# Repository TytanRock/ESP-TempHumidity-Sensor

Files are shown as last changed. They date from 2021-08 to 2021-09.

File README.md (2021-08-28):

# ESP Based IoT reporter
Project and Source files for custom PCB that implements various sensors with an ESP for reporting

## Sponsored by PCBWay
This project was graciously sponsored by [PCBWay](https://www.pcbway.com/) who provided boards of the product. I've used them before and enjoy their service, as they provide an affordable way of creating professional PCBs for projects such as this one. Check them out!

## Purpose
This is mostly a learning exercise for more complex boards, and tighter integration with cloud stuff.
I wanted to make a board that uses an ESP8266 to measure various things and report them to a cloud service.
This first version includes just measuring temperature and humidity throughout the house, with the option to expand and measure other things through I2C or Analog.

It includes an FTDI chip to program the ESP, the ESP itself, a temp/humidity sensor, and a Lithium-Ion charger with a connector for a Li-ion battery if I want to place it somewhere out of reach.
The repo will also include source code once I get my first batch of boards in.

## Board Views
I don't have the physical boards currently, but I think it's always nice to see what the boards look like without downloading and viewing it through eagle.
So here's the Top and Bottom boardview from Eagle.

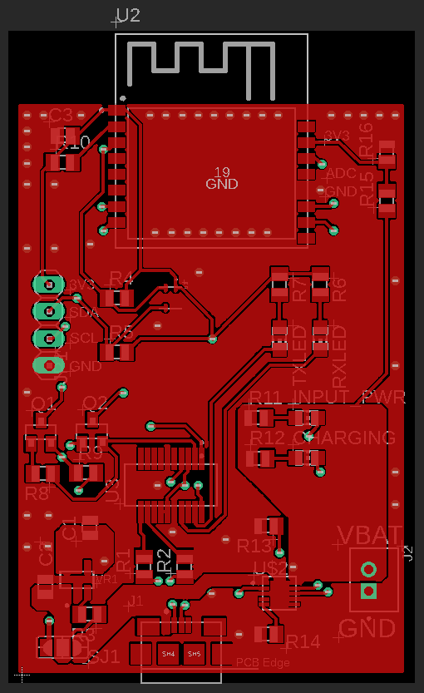
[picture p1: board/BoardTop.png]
Top Board

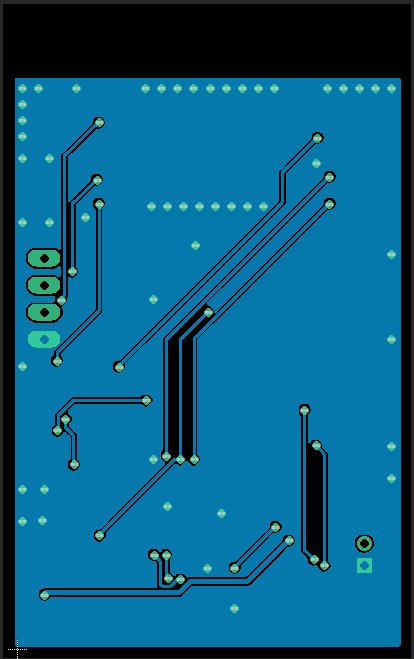
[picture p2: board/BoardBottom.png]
Bottom Board


Have fun with it if you think it's cool.

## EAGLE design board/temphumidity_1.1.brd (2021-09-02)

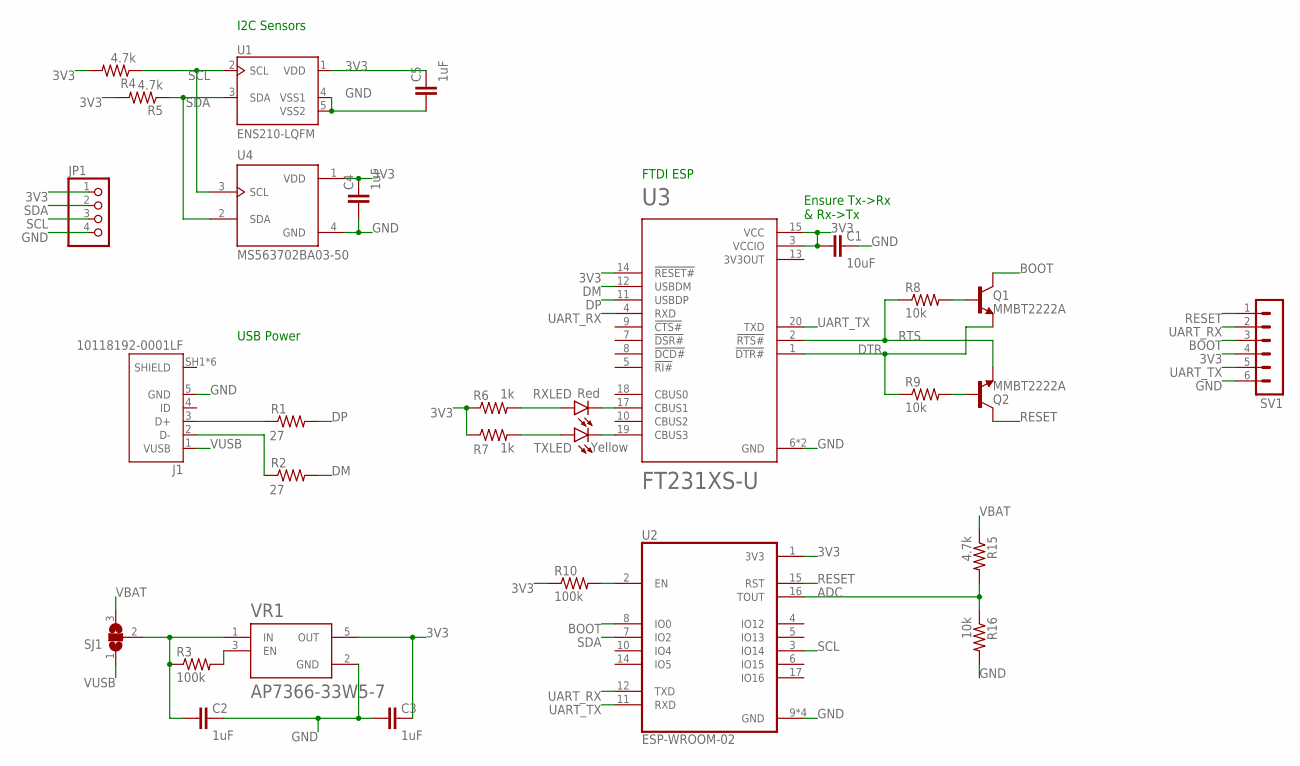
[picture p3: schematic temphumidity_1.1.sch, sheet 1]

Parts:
C1: 10uF; C0805
C2, C3, C4, C5: 1uF; C0805
J1: 10118192-0001LF; AMPHENOL_10118192-0001LF
JP1: PINHD-1X4; 1X04
Q1, Q2: MMBT2222A; SOT23
R1, R2: 27; R0805
R3, R10: 100k; R0805
R4, R5, R15: 4.7k; R0805
R6, R7: 1k; R0805
R8, R9, R16: 10k; R0805
RXLED: Red; CHIP-LED0805
SJ1: SJ2W; SJ_2
SV1: MA06-1
TXLED: Yellow; CHIP-LED0805
U1: ENS210-LQFM; SON95P200X200X80-5N160X70
U2: ESP-WROOM-02; MODULE_ESP-WROOM-02
U3: FT231XS-U; SOP63P600X175-20N
U4: MS563702BA03-50; TE_MS563702BA03-50
VR1: AP7366-33W5-7; SOT95P285X140-5N

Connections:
3V3: C1.2, C3.1, C4.1, C5.1, JP1.1, R4.2, R5.2, R6.1, R7.1, R10.1, SV1.4, U1.1 (VDD), U2.1 (3V3), U3.3 (VCCIO), U3.14 (!RESET#), U3.15 (VCC), U4.1 (VDD), VR1.5 (OUT)
3V3OUT: U3.13 (3V3OUT)
ADC: R15.2, R16.1, U2.16 (TOUT)
BOOT: Q1.3 (C), SV1.3, U2.8 (IO0)
DM: R2.2, U3.12 (USBDM)
DP: R1.2, U3.11 (USBDP)
DTR: Q1.2 (E), R9.1, U3.1 (!DTR#)
GND: C1.1, C2.1, C3.2, C4.2, C5.2, J1.5 (GND), JP1.4, R16.2, SV1.6, U1.4 (VSS1), U1.5 (VSS2), U2.9 (GND), U2.13 (GND), U2.18 (GND), U2.19 (GND), U3.6 (GND), U3.16 (GND), U4.4 (GND), VR1.2 (GND); also elsewhere on the board
unnamed: J1.3 (D+), R1.1
unnamed: J1.2 (D-), R2.1
unnamed: R3.2, VR1.3 (EN)
unnamed: RXLED.C, U3.17 (CBUS1)
unnamed: TXLED.C, U3.19 (CBUS3)
unnamed: R6.2, RXLED.A
unnamed: R7.2, TXLED.A
unnamed: Q1.1 (B), R8.2
unnamed: Q2.1 (B), R9.2
unnamed: R10.2, U2.2 (EN)
RESET: Q2.3 (C), SV1.1, U2.15 (RST)
RTS: Q2.2 (E), R8.1, U3.2 (!RTS#)
SCL: JP1.3, R4.1, U1.2 (SCL), U2.3 (IO14), U4.3 (SCL)
SDA: JP1.2, R5.1, U1.3 (SDA), U2.7 (IO2), U4.2 (SDA)
SELECTEDVOLTAGE: C2.2, R3.1, SJ1.2, VR1.1 (IN)
UART_RX: SV1.2, U2.12 (TXD), U3.4 (RXD)
UART_TX: SV1.5, U2.11 (RXD), U3.20 (TXD)
VBAT: R15.1, SJ1.3; also elsewhere on the board
VUSB: J1.1 (VUSB), SJ1.1; also elsewhere on the board

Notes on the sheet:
Ensure Tx->Rx & Rx->Tx
USB Power
FTDI ESP
I2C Sensors

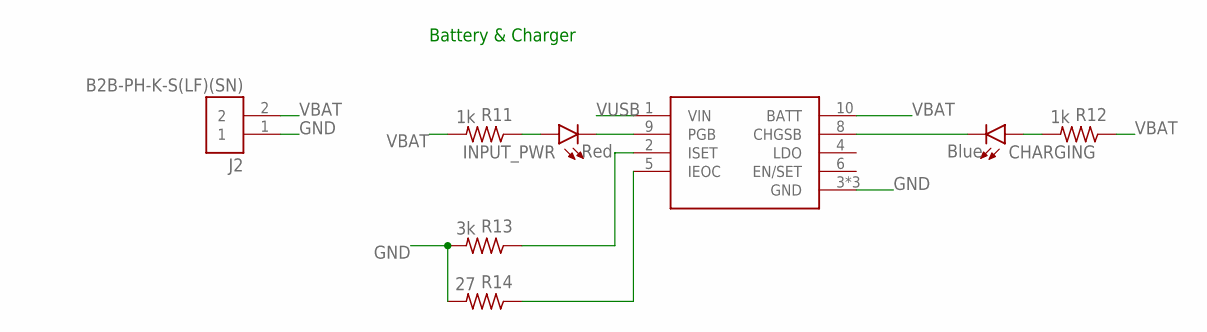
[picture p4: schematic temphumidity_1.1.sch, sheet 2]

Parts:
CHARGING: Blue; CHIP-LED0805
INPUT_PWR: Red; CHIP-LED0805
J2: B2B-PH-K-S(LF)(SN); JST_B2B-PH-K-S(LF)(SN)
R11, R12: 1k; R0805
R13: 3k; R0805
R14: 27; R0805
U$2: RT9532GQW; SON50P300X300X80-11N

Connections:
GND: J2.1, R13.2, R14.2, U$2.3 (GND), U$2.7 (GND), U$2.11 (GND); also elsewhere on the board
unnamed: INPUT_PWR.C, U$2.9 (PGB)
unnamed: CHARGING.C, U$2.8 (CHGSB)
unnamed: INPUT_PWR.A, R11.1
unnamed: R13.1, U$2.2 (ISET)
unnamed: CHARGING.A, R12.2
unnamed: R14.1, U$2.5 (IEOC)
VBAT: J2.2, R11.2, R12.1, U$2.10 (BATT); also elsewhere on the board
VUSB: U$2.1 (VIN); also elsewhere on the board

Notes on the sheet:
Battery & Charger

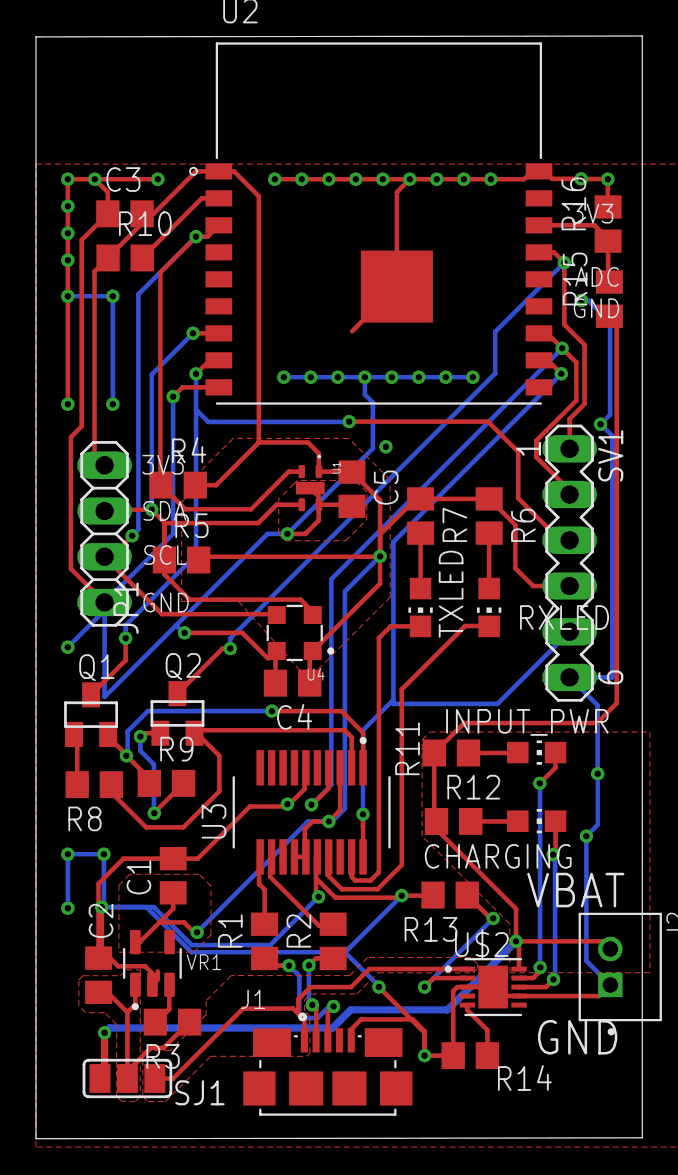
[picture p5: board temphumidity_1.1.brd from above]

Board: 2 copper layers, 33.7 x 61.3 mm, 38 parts (0 on the bottom side), 32 nets.

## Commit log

2021-08-22 Initial Commit
    V1.0 sent out to PCBway for production
    [temphumidity_1.0.brd, temphumidity_1.0.sch]
2021-08-22 Added bom for v1.0
2021-08-22 Moved board docs to board subdirectory & added website code
    [temphumidity_1.0.brd, temphumidity_1.0.sch]
2021-08-25 Did some revisions to beef up connection pathways and reduce radiation
    Further work will be done on 1.1 until I get the boards in and can make
    decisions on what major things to change
    [temphumidity_1.1.brd, temphumidity_1.1.sch]
2021-08-25 Added Sponsorship Snippet
    PCBWay contacted me to ask if I wanted them to sponsor this project, and I did. So I added this.
2021-08-28 More revisions on 1.1, added pictures for Readme
    [temphumidity_1.1.brd, temphumidity_1.1.sch]
2021-08-29 Wrote spring application to make use of sql database
    [temphumidity_1.1.brd, temphumidity_1.1.sch]
2021-09-02 More board work
    [temphumidity_1.1.brd]
2021-09-02 Added breakout so old programmers can program new boards
    [temphumidity_1.1.brd, temphumidity_1.1.sch]
